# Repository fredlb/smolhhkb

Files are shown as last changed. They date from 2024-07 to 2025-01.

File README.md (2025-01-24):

# smolhhkb
A small 40% keyboard with same asymetrical bottom row as hhkb.

smolhhkb
Pictured is a one-off prototype:  
Top: Polycarbonate  
Bottom: Aluminium, white anodization  
Weight: Copper  

The little window down to the PCB is resin printed, with an oring to attach it to the top piece.

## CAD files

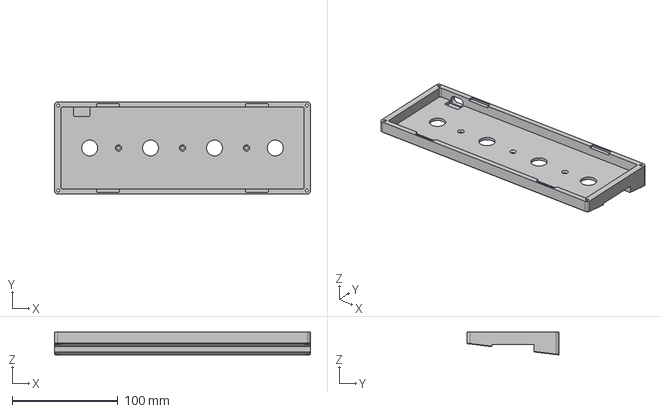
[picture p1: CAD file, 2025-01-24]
case/smolhhkb_bottom.step
241.6 x 87.1 x 21.6 mm

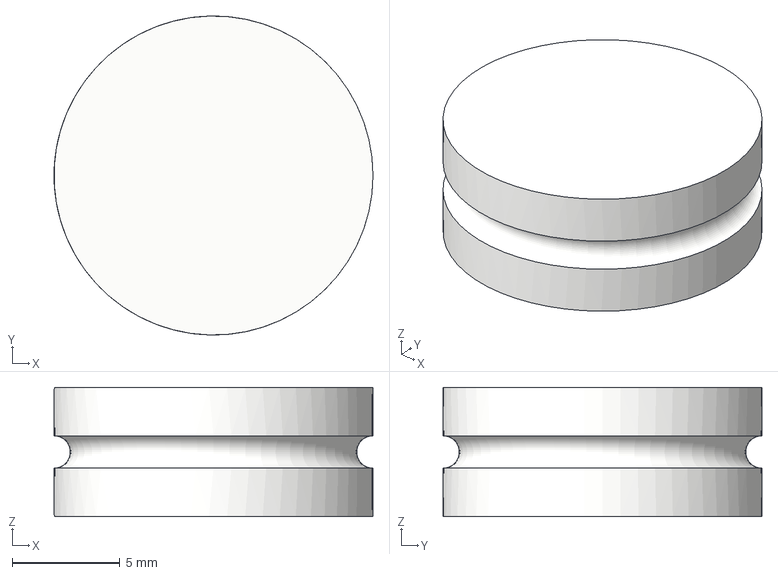
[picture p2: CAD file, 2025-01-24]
case/smolhhkb_window.step
14.8 x 14.8 x 6.00 mm

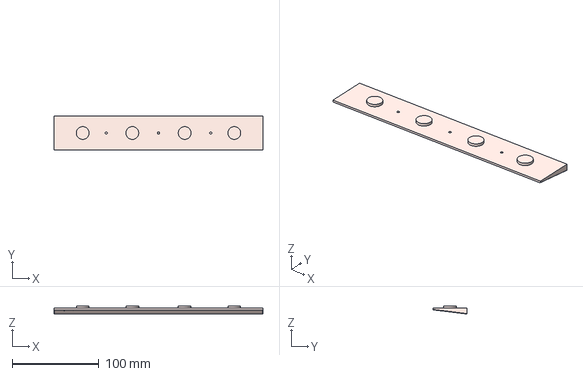
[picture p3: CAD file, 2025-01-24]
case/smolhhkb_weight.step
241.6 x 39.6 x 9.41 mm

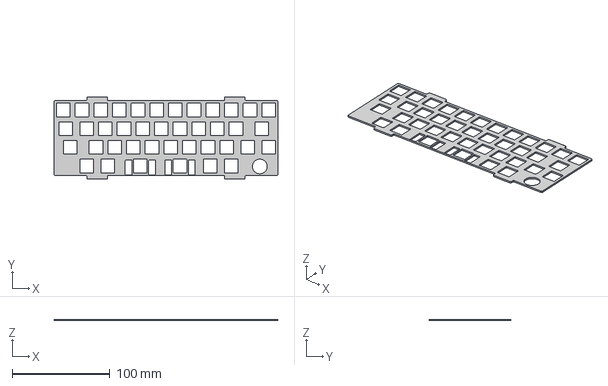
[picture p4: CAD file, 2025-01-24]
case/smolhhkb_plate.step
228.6 x 83.8 x 1.50 mm

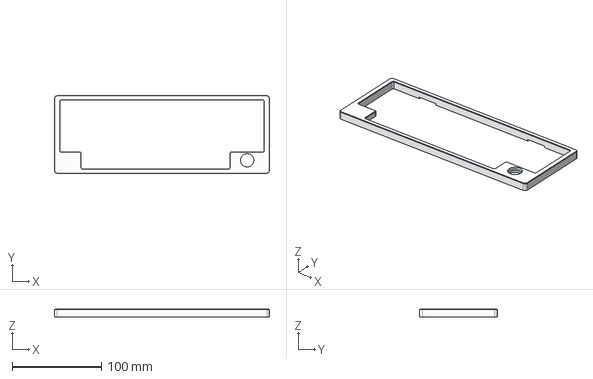
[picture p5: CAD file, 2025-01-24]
case/smolhhkb_top.step
241.6 x 87.1 x 8.55 mm

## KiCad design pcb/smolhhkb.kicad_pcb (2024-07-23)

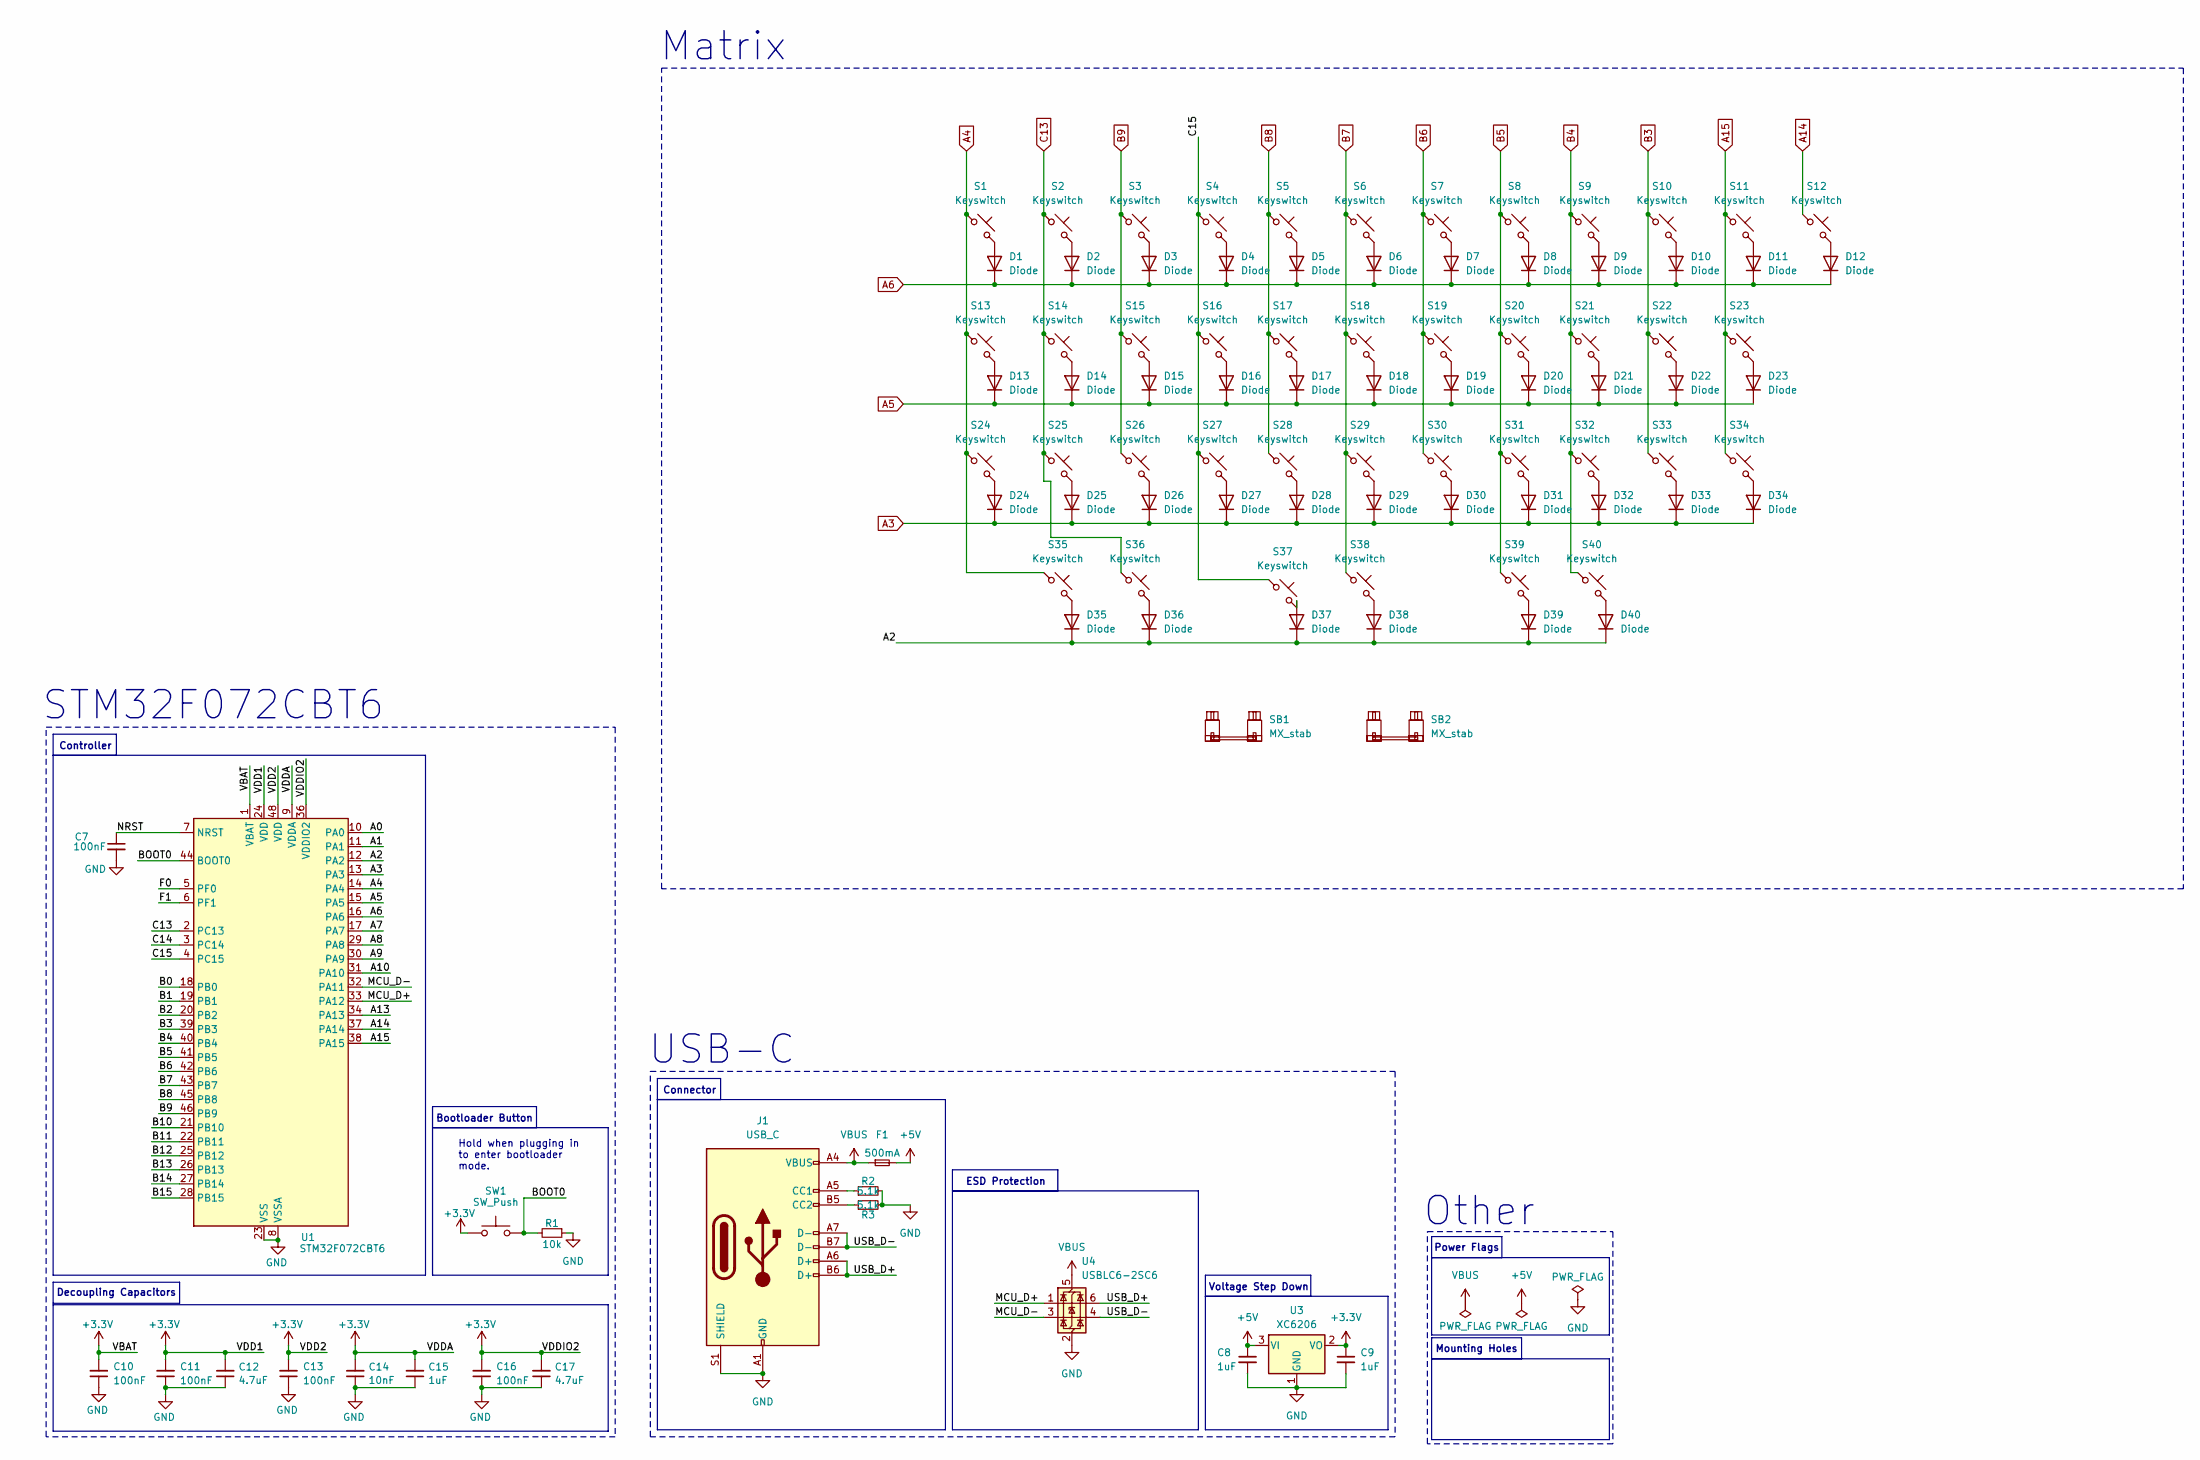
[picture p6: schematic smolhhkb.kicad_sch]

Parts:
C7: 100nF; Capacitor_0402; LCSC C307331
C8, C9: 1uF; Capacitor_0402; LCSC C52923
C10, C11, C13, C16: 100nF; Capacitor_0402; MPN CL05B104KB54PNC; LCSC C307331
C12, C17: 4.7uF; Capacitor_0402; MPN CL05A475MP5NRNC; LCSC C23733
C14: 10nF; Capacitor_0402; MPN CL05B103KB5NNNC; LCSC C15195
C15: 1uF; Capacitor_0402; MPN CL05A105KA5NQNC; LCSC C52923
D1, D2, D3, D4, D5, D6, D7, D8, D9, D10, D11, D12, D13, D14, D15, D16, D17, D18, D19, D20, D21, D22, D23, D24, D25, D26, D27, D28, D29, D30, D31, D32, D33, D34, D35, D36, D37, D38, D39, D40: Diode; Diode_SOD-123
F1: 500mA; Fuse_0603; LCSC C210357
J1: USB_C; USB_C_HRO_TYPE-C-31-M-12; LCSC C165948
R1: 10k; Resistor_0402; LCSC C25744
R2, R3: 5.1k; Resistor_0402; LCSC C25905
S1, S2, S3, S4, S5, S6, S7, S8, S9, S10, S11, S12, S14, S15, S16, S17, S18, S19, S20, S21, S22, S25, S26, S27, S28, S29, S30, S31, S32, S34, S35, S37, S38, S40: Keyswitch; SW_MX_1u
S13, S33, S36, S39: Keyswitch; SW_MX_1.25u
S23, S24: Keyswitch; SW_MX_1.75u
SB1: MX_stab; STAB_MX_2.25u
SB2: MX_stab; STAB_MX_2u
SW1: SW_Push; Button_TL3342; LCSC C115351
U1: STM32F072CBT6; Package_LQFP-48_7x7mm_P0.5; LCSC C81720
U3: XC6206; Voltage_SOT-23; LCSC C5446
U4: USBLC6-2SC6; ESD_SOT-23-6; LCSC C2827654

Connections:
+3.3V: C9.1, C10.2, C11.2, C12.2, C13.2, C14.2, C15.2, C16.2, C17.2, SW1.1, U1.1 (VBAT), U1.9 (VDDA), U1.24 (VDD), U1.36 (VDDIO2), U1.48 (VDD), U3.2 (VO)
+5V: C8.1, F1.2, U3.3 (VI)
/A0: U1.10 (PA0)
/A1: U1.11 (PA1)
/A2: D35.1 (K), D36.1 (K), D37.1 (K), D38.1 (K), D39.1 (K), D40.1 (K), U1.12 (PA2)
/A7: U1.17 (PA7)
/A8: U1.29 (PA8)
/A9: U1.30 (PA9)
/A10: U1.31 (PA10)
/A13: U1.34 (PA13)
/B0: U1.18 (PB0)
/B1: U1.19 (PB1)
/B2: U1.20 (PB2)
/B10: U1.21 (PB10)
/B11: U1.22 (PB11)
/B12: U1.25 (PB12)
/B13: U1.26 (PB13)
/B14: U1.27 (PB14)
/B15: U1.28 (PB15)
/BOOT0: R1.2, SW1.2, U1.44 (BOOT0)
/C14: U1.3 (PC14)
/C15: S4.1, S16.1, S27.1, S37.1, U1.4 (PC15)
/F0: U1.5 (PF0)
/F1: U1.6 (PF1)
/MCU_D+: U1.33 (PA12), U4.1 (I/O1)
/MCU_D-: U1.32 (PA11), U4.3 (I/O2)
/NRST: C7.1, U1.7 (NRST)
/USB_D+: J1.A6 (D+), J1.B6 (D+), U4.6 (I/O1)
/USB_D-: J1.A7 (D-), J1.B7 (D-), U4.4 (I/O2)
A3: D24.1 (K), D25.1 (K), D26.1 (K), D27.1 (K), D28.1 (K), D29.1 (K), D30.1 (K), D31.1 (K), D32.1 (K), D33.1 (K), D34.1 (K), U1.13 (PA3)
A4: S1.1, S13.1, S24.1, S35.1, U1.14 (PA4)
A5: D13.1 (K), D14.1 (K), D15.1 (K), D16.1 (K), D17.1 (K), D18.1 (K), D19.1 (K), D20.1 (K), D21.1 (K), D22.1 (K), D23.1 (K), U1.15 (PA5)
A6: D1.1 (K), D2.1 (K), D3.1 (K), D4.1 (K), D5.1 (K), D6.1 (K), D7.1 (K), D8.1 (K), D9.1 (K), D10.1 (K), D11.1 (K), D12.1 (K), U1.16 (PA6)
A14: S12.1, U1.37 (PA14)
A15: S11.1, S23.1, S34.1, U1.38 (PA15)
B3: S10.1, S22.1, S33.1, U1.39 (PB3)
B4: S9.1, S21.1, S32.1, S40.1, U1.40 (PB4)
B5: S8.1, S20.1, S31.1, S39.1, U1.41 (PB5)
B6: S7.1, S19.1, S30.1, U1.42 (PB6)
B7: S6.1, S18.1, S29.1, S38.1, U1.43 (PB7)
B8: S5.1, S17.1, S28.1, U1.45 (PB8)
B9: S3.1, S15.1, S26.1, U1.46 (PB9)
C13: S2.1, S14.1, S25.1, S36.1, U1.2 (PC13)
GND: C7.2, C8.2, C9.2, C10.1, C11.1, C12.1, C13.1, C14.1, C15.1, C16.1, C17.1, J1.A1 (GND), J1.A12 (GND), J1.B1 (GND), J1.B12 (GND), J1.S1 (SHIELD), R1.1, R2.2, R3.2, U1.8 (VSSA), U1.23 (VSS), U1.35 (VSS), U1.47 (VSS), U3.1 (GND), U4.2 (GND)
unnamed: D1.2 (A), S1.2
unnamed: D2.2 (A), S2.2
unnamed: D3.2 (A), S3.2
unnamed: D4.2 (A), S4.2
unnamed: D5.2 (A), S5.2
unnamed: D6.2 (A), S6.2
unnamed: D7.2 (A), S7.2
unnamed: D8.2 (A), S8.2
unnamed: D9.2 (A), S9.2
unnamed: D10.2 (A), S10.2
unnamed: D11.2 (A), S11.2
unnamed: D12.2 (A), S12.2
unnamed: D13.2 (A), S13.2
unnamed: D14.2 (A), S14.2
unnamed: D15.2 (A), S15.2
unnamed: D16.2 (A), S16.2
unnamed: D17.2 (A), S17.2
unnamed: D18.2 (A), S18.2
unnamed: D19.2 (A), S19.2
unnamed: D20.2 (A), S20.2
unnamed: D21.2 (A), S21.2
unnamed: D22.2 (A), S22.2
unnamed: D23.2 (A), S23.2
unnamed: D24.2 (A), S24.2
unnamed: D25.2 (A), S25.2
unnamed: D26.2 (A), S26.2
unnamed: D27.2 (A), S27.2
unnamed: D28.2 (A), S28.2
unnamed: D29.2 (A), S29.2
unnamed: D30.2 (A), S30.2
unnamed: D31.2 (A), S31.2
unnamed: D32.2 (A), S32.2
unnamed: D33.2 (A), S33.2
unnamed: D34.2 (A), S34.2
unnamed: D35.2 (A), S35.2
unnamed: D36.2 (A), S36.2
unnamed: D37.2 (A), S37.2
unnamed: D38.2 (A), S38.2
unnamed: D39.2 (A), S39.2
unnamed: D40.2 (A), S40.2
unnamed: J1.A5 (CC1), R2.1
unnamed: J1.B5 (CC2), R3.1
VBUS: F1.1, J1.A4 (VBUS), J1.A9 (VBUS), J1.B4 (VBUS), J1.B9 (VBUS), U4.5 (VBUS)

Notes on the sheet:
Hold when plugging in to enter bootloader mode.
STM32F072CBT6
USB-C
Mounting Holes
Decoupling Capacitors
Controller
ESD Protection
Power Flags
Voltage Step Down
Other
Bootloader Button
Matrix
Connector

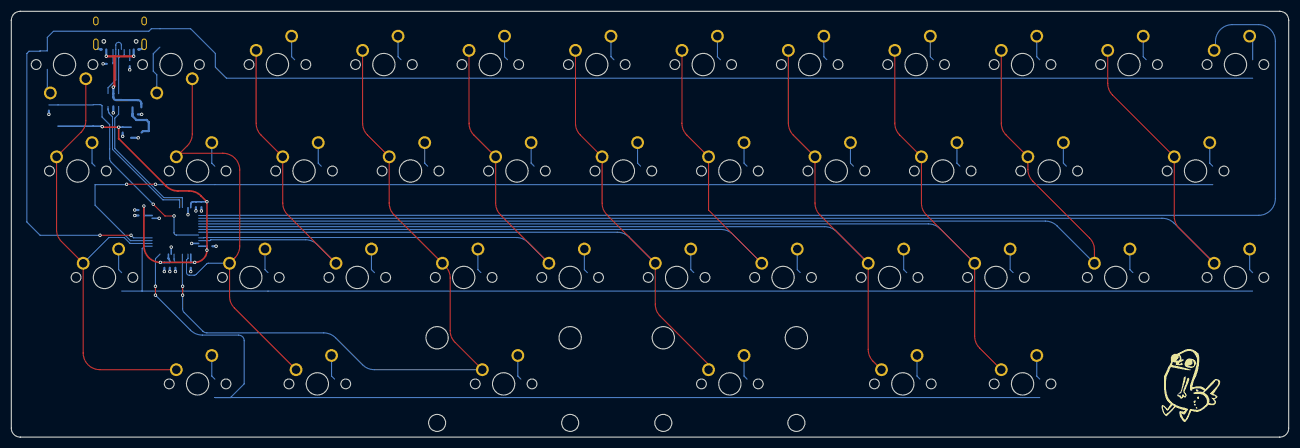
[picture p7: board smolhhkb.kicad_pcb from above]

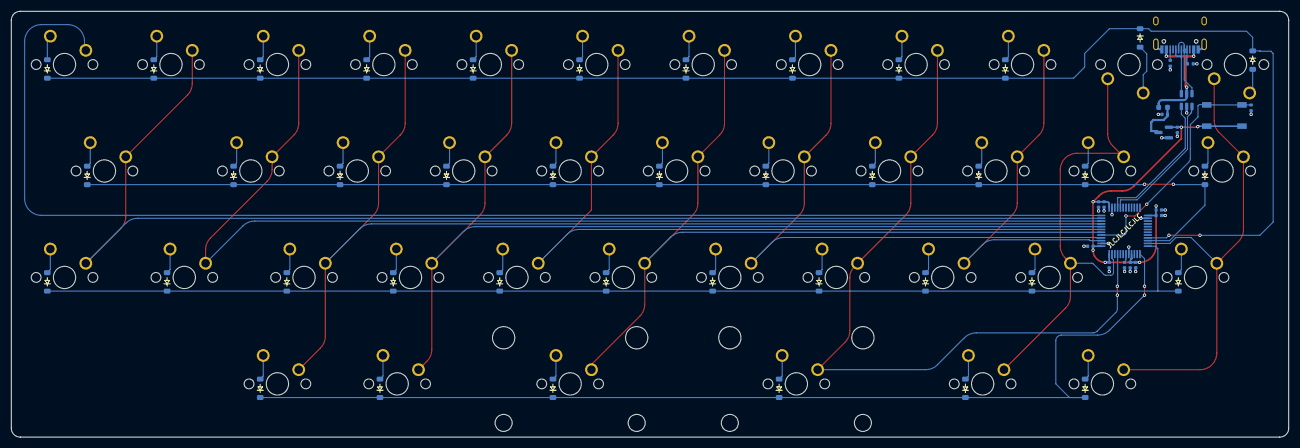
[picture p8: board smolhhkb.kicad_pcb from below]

Board: 4 copper layers, 228.6 x 76.2 mm, 102 parts (60 on the bottom side), 68 nets.

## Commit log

2024-07-23 Fine tuning silkscreen placement
    [smolhhkb.kicad_pcb]
2025-01-24 case files
    [smolhhkb_bottom.step, smolhhkb_plate.step, smolhhkb_top.step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]
